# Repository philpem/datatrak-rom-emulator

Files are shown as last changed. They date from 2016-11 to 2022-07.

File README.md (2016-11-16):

EPROM Emulator for Datatrak Locator
===================================

This is a plug-in card which replaces the Datatrak "B7415" plug-in ROM card
used with the Locator Mk. II. Its purpose is to allow easier development of
alternative firmware for the Datatrak Locator II, and reverse engineering
of the hardware.

It consists of a 256Kx16 SRAM (512KiB) which can be loaded via an FTDI
FT240X USB serial FIFO and a Xilinx XC95144XL CPLD. The CPLD is programmed
using a JTAG cable.

Mod wires
---------
Rev 'A' boards require a 'mod wire' to be fitted between pin 135 of IC2
(the Xilinx CPLD) and either pin 10 of the SRAM or pin 37 of U3 (the
uppermost voltage level translator).

This wire carries D8 (level translated) from the level translator and SRAM
to the CPLD. Failure to install this wire will prevent D8 from being loaded
by the CPLD.

Known limitations
-----------------

  * The SRAM is powered from the target. Disconnecting target power will
    cause the loss of the data in the emulated EPROM.

    * It might be a good idea to break the power supply to the SRAM and
      feed it via two Schottky diodes: one from +3V3 and one from the FTDI's
      3V output.
      This way, the RAM will be maintained as long as either the USB or
      target is powered.

CPLD configuration
------------------
The CPLD must be programmed before the ROM emulator can be used.

  1. Apply 5V power through the DIN41612 target connector.
  2. 5V power is applied to pins A1 and B1 of the connector, while ground
     is applied to pins A16 and B16.
  3. 3.3V DC should be present on the output of voltage regulator IC1, and
     on JTAG connector X3.
  4. Connect a Xilinx Platform Cable USB (if using iMPACT) or Altera USB
     JTAG cable (if using OpenOCD) to JTAG connector X3.
  5. Use Xilinx iMPACT, OpenOCD or similar to program the CPLD.
    - It's probably easiest to use iMPACT.
  6. Disconnect the JTAG cable, 5V power, etc.
  7. Plug the pod into the Locator and load it.

FT240X configuration
--------------------
The FT240X needs to be programmed with FT-PROG.

  * Program CBUS5 to output the 24MHz clock.
    * This is used by the CPLD as a clock for the state machine.

Exfiltration mode
-----------------
This mode allows the target to access a specially-designated port to use as
a return-channel to the emulation control PC. Essentially, this is like a
secondary, lightweight, "printf".

When an access is made in a specially designated range (address lines
A8..A17 match a preset value), the value of address lines A0 through A7 is
latched, then sent to the FT240X as "write data".

This data may be read by the host PC at its convenience.

It would be nice to add an "infiltration mode" to send data from the PC to
the Locator, but "printf" was a higher priority.

Load protocol
-------------

The data in the FTDI buffer consists of Commands and Data. These are the
Commands which the state machine currently recognises:

  * 0b0000\_0000: NOP
    * Does nothing.
    * Used to reset the state machine to a known state.

  * 0b0000\_0001: Reset Memory Address Counter
    * Resets the memory address to zero

  * 0b0001\_Xemm: Set Mode
    * X: don't care
    * e: Exfiltration mode on/off
      * 0: Off
      * 1: On
    * mm: Mode
      * 00: Run
      * 01: Load

  * 0b0010\_nnnn: Write _nnnn_ words
    * nnnn: Number of words to write
    * Followed by _nnnn_ words of ROM data

  * 0b0100\_xxEE: Set Exfiltration Address
    * EE: Top two bits of exfiltration address (b17..b16)
    * Followed by a byte which contains bits 15..8 of the exfiltration
      address
    * Bits 7..0 are the exfiltration data itself

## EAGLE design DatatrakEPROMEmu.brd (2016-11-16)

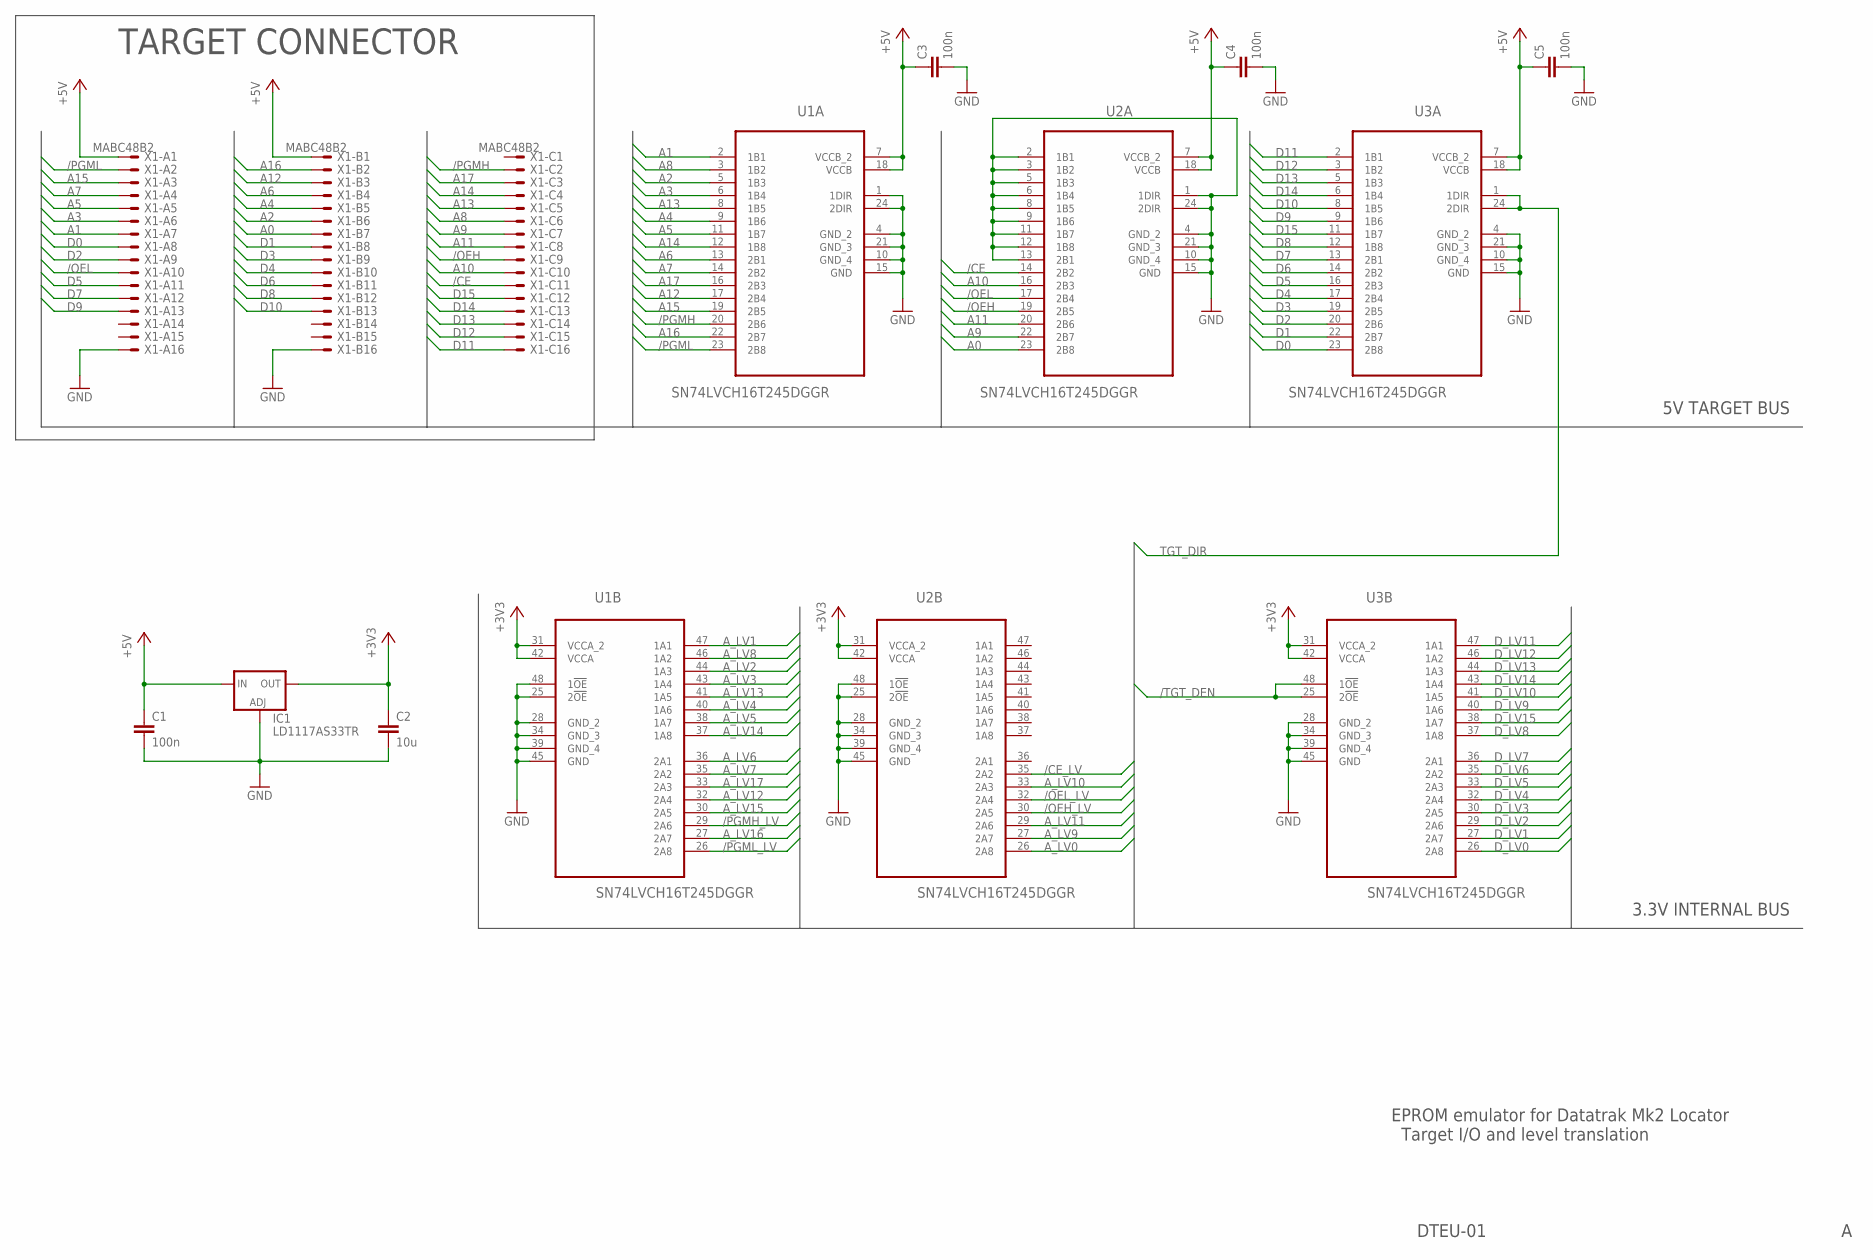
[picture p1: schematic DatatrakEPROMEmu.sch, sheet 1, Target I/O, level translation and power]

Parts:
C1, C3, C4, C5: 100n; C0805
C2: 10u; C0805
IC1: LD1117AS33TR; SOT223
U1, U2, U3: SN74LVCH16T245DGGR; SOP50P810X120-48N
X1: MABC48B2

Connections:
+3V3: C2.1, IC1.4 (OUT), U1.31 (VCCA_2), U1.42 (VCCA), U2.31 (VCCA_2), U2.42 (VCCA), U3.31 (VCCA_2), U3.42 (VCCA); also elsewhere on the board
+5V: C1.1, C3.1, C4.1, C5.1, IC1.3 (IN), U1.7 (VCCB_2), U1.18 (VCCB), U2.7 (VCCB_2), U2.18 (VCCB), U3.7 (VCCB_2), U3.18 (VCCB), X1.A1, X1.B1
/CE: U2.14 (2B2), X1.C11
/CE_LV: U2.35 (2A2); also elsewhere on the board
/OEH: U2.19 (2B5), X1.C9
/OEH_LV: U2.30 (2A5); also elsewhere on the board
/OEL: U2.17 (2B4), X1.A10
/OEL_LV: U2.32 (2A4); also elsewhere on the board
/PGMH: U1.20 (2B6), X1.C2
/PGMH_LV: U1.29 (2A6); also elsewhere on the board
/PGML: U1.23 (2B8), X1.A2
/PGML_LV: U1.26 (2A8); also elsewhere on the board
/TGT_DEN: U3.25 (2!OE), U3.48 (1!OE); also elsewhere on the board
A0: U2.23 (2B8), X1.B7
A1: U1.2 (1B1), X1.A7
A2: U1.5 (1B3), X1.B6
A3: U1.6 (1B4), X1.A6
A4: U1.9 (1B6), X1.B5
A5: U1.11 (1B7), X1.A5
A6: U1.13 (2B1), X1.B4
A7: U1.14 (2B2), X1.A4
A8: U1.3 (1B2), X1.C6
A9: U2.22 (2B7), X1.C7
A10: U2.16 (2B3), X1.C10
A11: U2.20 (2B6), X1.C8
A12: U1.17 (2B4), X1.B3
A13: U1.8 (1B5), X1.C5
A14: U1.12 (1B8), X1.C4
A15: U1.19 (2B5), X1.A3
A16: U1.22 (2B7), X1.B2
A17: U1.16 (2B3), X1.C3
A_LV0: U2.26 (2A8); also elsewhere on the board
A_LV1: U1.47 (1A1); also elsewhere on the board
A_LV2: U1.44 (1A3); also elsewhere on the board
A_LV3: U1.43 (1A4); also elsewhere on the board
A_LV4: U1.40 (1A6); also elsewhere on the board
A_LV5: U1.38 (1A7); also elsewhere on the board
A_LV6: U1.36 (2A1); also elsewhere on the board
A_LV7: U1.35 (2A2); also elsewhere on the board
A_LV8: U1.46 (1A2); also elsewhere on the board
A_LV9: U2.27 (2A7); also elsewhere on the board
A_LV10: U2.33 (2A3); also elsewhere on the board
A_LV11: U2.29 (2A6); also elsewhere on the board
A_LV12: U1.32 (2A4); also elsewhere on the board
A_LV13: U1.41 (1A5); also elsewhere on the board
A_LV14: U1.37 (1A8); also elsewhere on the board
A_LV15: U1.30 (2A5); also elsewhere on the board
A_LV16: U1.27 (2A7); also elsewhere on the board
A_LV17: U1.33 (2A3); also elsewhere on the board
D0: U3.23 (2B8), X1.A8
D1: U3.22 (2B7), X1.B8
D2: U3.20 (2B6), X1.A9
D3: U3.19 (2B5), X1.B9
D4: U3.17 (2B4), X1.B10
D5: U3.16 (2B3), X1.A11
D6: U3.14 (2B2), X1.B11
D7: U3.13 (2B1), X1.A12
D8: U3.12 (1B8), X1.B12
D9: U3.9 (1B6), X1.A13
D10: U3.8 (1B5), X1.B13
D11: U3.2 (1B1), X1.C16
D12: U3.3 (1B2), X1.C15
D13: U3.5 (1B3), X1.C14
D14: U3.6 (1B4), X1.C13
D15: U3.11 (1B7), X1.C12
D_LV0: U3.26 (2A8); also elsewhere on the board
D_LV1: U3.27 (2A7); also elsewhere on the board
D_LV2: U3.29 (2A6); also elsewhere on the board
D_LV3: U3.30 (2A5); also elsewhere on the board
D_LV4: U3.32 (2A4); also elsewhere on the board
D_LV5: U3.33 (2A3); also elsewhere on the board
D_LV6: U3.35 (2A2); also elsewhere on the board
D_LV7: U3.36 (2A1); also elsewhere on the board
D_LV8: U3.37 (1A8); also elsewhere on the board
D_LV9: U3.40 (1A6); also elsewhere on the board
D_LV10: U3.41 (1A5); also elsewhere on the board
D_LV11: U3.47 (1A1); also elsewhere on the board
D_LV12: U3.46 (1A2); also elsewhere on the board
D_LV13: U3.44 (1A3); also elsewhere on the board
D_LV14: U3.43 (1A4); also elsewhere on the board
D_LV15: U3.38 (1A7); also elsewhere on the board
GND: C1.2, C2.2, C3.2, C4.2, C5.2, IC1.1 (ADJ), U1.1 (1DIR), U1.4 (GND_2), U1.10 (GND_4), U1.15 (GND), U1.21 (GND_3), U1.24 (2DIR), U1.25 (2!OE), U1.28 (GND_2), U1.34 (GND_3), U1.39 (GND_4), U1.45 (GND), U1.48 (1!OE), U2.1 (1DIR), U2.2 (1B1), U2.3 (1B2), U2.4 (GND_2), U2.5 (1B3), U2.6 (1B4), U2.8 (1B5), U2.9 (1B6), U2.10 (GND_4), U2.11 (1B7), U2.12 (1B8), U2.13 (2B1), U2.15 (GND), U2.21 (GND_3), U2.24 (2DIR), U2.25 (2!OE), U2.28 (GND_2), U2.34 (GND_3), U2.39 (GND_4), U2.45 (GND), U2.48 (1!OE), U3.4 (GND_2), U3.10 (GND_4), U3.15 (GND), U3.21 (GND_3), U3.28 (GND_2), U3.34 (GND_3), U3.39 (GND_4), U3.45 (GND), X1.A16, X1.B16; also elsewhere on the board
TGT_DIR: U3.1 (1DIR), U3.24 (2DIR); also elsewhere on the board

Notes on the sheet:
TARGET CONNECTOR
5V TARGET BUS
3.3V INTERNAL BUS
DTEU-01
EPROM emulator for Datatrak Mk2 Locator Target I/O and level translation

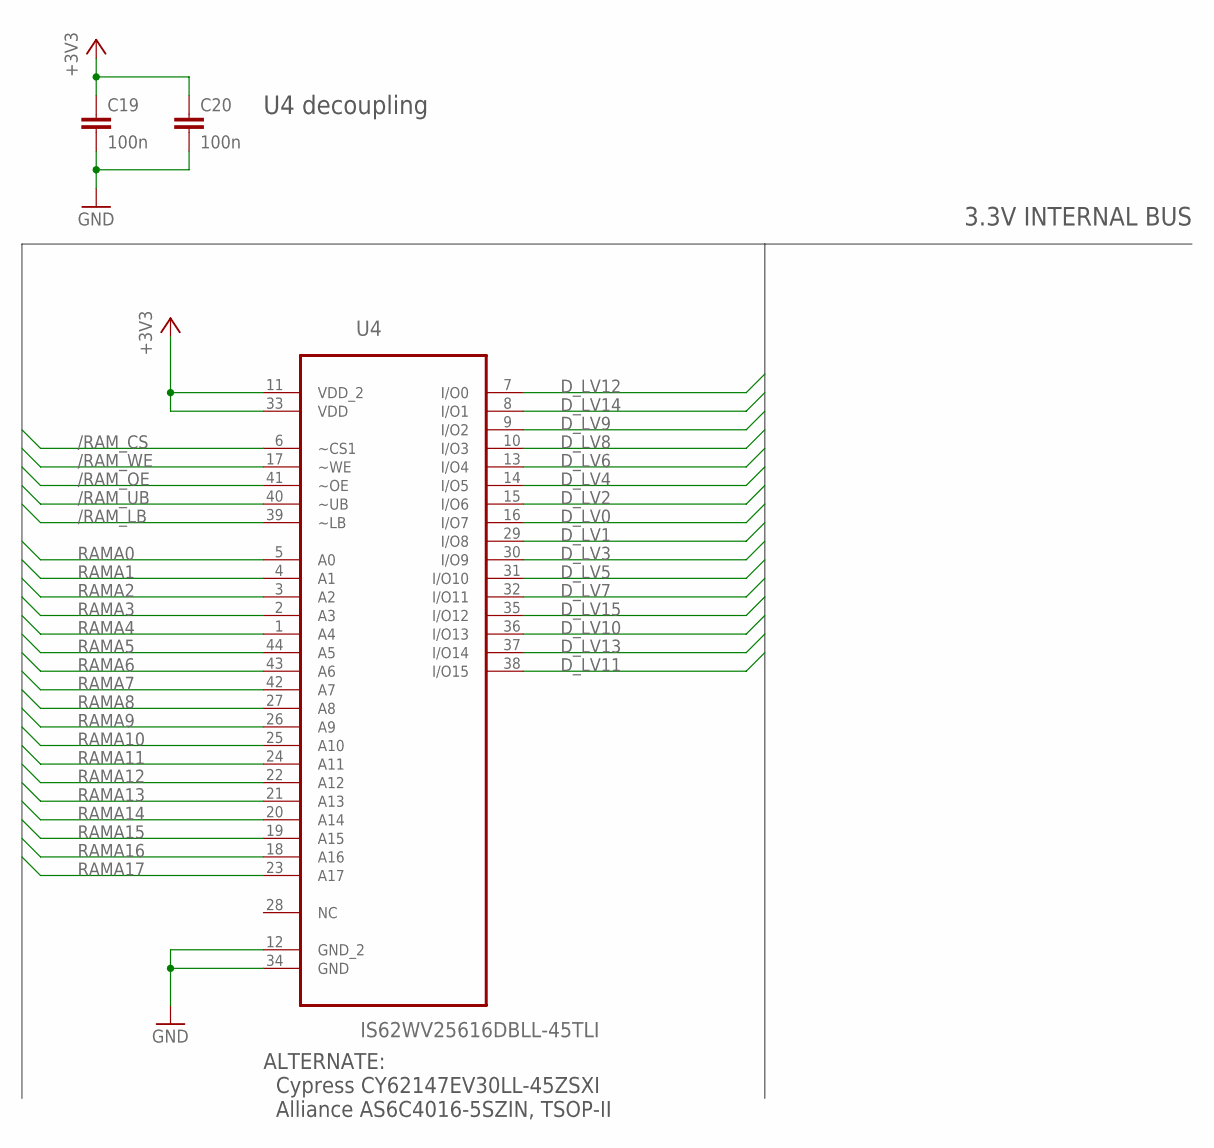
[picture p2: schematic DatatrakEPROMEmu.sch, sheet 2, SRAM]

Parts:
C19, C20: 100n; C0805
U4: IS62WV25616DBLL-45TLI; SOP80P1176X120-44N

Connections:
+3V3: C19.1, C20.1, U4.11 (VDD_2), U4.33 (VDD); also elsewhere on the board
/RAM_CS: U4.6 (~CS1); also elsewhere on the board
/RAM_LB: U4.39 (~LB); also elsewhere on the board
/RAM_OE: U4.41 (~OE); also elsewhere on the board
/RAM_UB: U4.40 (~UB); also elsewhere on the board
/RAM_WE: U4.17 (~WE); also elsewhere on the board
D_LV0: U4.16 (I/O7); also elsewhere on the board
D_LV1: U4.29 (I/O8); also elsewhere on the board
D_LV2: U4.15 (I/O6); also elsewhere on the board
D_LV3: U4.30 (I/O9); also elsewhere on the board
D_LV4: U4.14 (I/O5); also elsewhere on the board
D_LV5: U4.31 (I/O10); also elsewhere on the board
D_LV6: U4.13 (I/O4); also elsewhere on the board
D_LV7: U4.32 (I/O11); also elsewhere on the board
D_LV8: U4.10 (I/O3); also elsewhere on the board
D_LV9: U4.9 (I/O2); also elsewhere on the board
D_LV10: U4.36 (I/O13); also elsewhere on the board
D_LV11: U4.38 (I/O15); also elsewhere on the board
D_LV12: U4.7 (I/O0); also elsewhere on the board
D_LV13: U4.37 (I/O14); also elsewhere on the board
D_LV14: U4.8 (I/O1); also elsewhere on the board
D_LV15: U4.35 (I/O12); also elsewhere on the board
GND: C19.2, C20.2, U4.12 (GND_2), U4.34 (GND); also elsewhere on the board
RAMA0: U4.5 (A0); also elsewhere on the board
RAMA1: U4.4 (A1); also elsewhere on the board
RAMA2: U4.3 (A2); also elsewhere on the board
RAMA3: U4.2 (A3); also elsewhere on the board
RAMA4: U4.1 (A4); also elsewhere on the board
RAMA5: U4.44 (A5); also elsewhere on the board
RAMA6: U4.43 (A6); also elsewhere on the board
RAMA7: U4.42 (A7); also elsewhere on the board
RAMA8: U4.27 (A8); also elsewhere on the board
RAMA9: U4.26 (A9); also elsewhere on the board
RAMA10: U4.25 (A10); also elsewhere on the board
RAMA11: U4.24 (A11); also elsewhere on the board
RAMA12: U4.22 (A12); also elsewhere on the board
RAMA13: U4.21 (A13); also elsewhere on the board
RAMA14: U4.20 (A14); also elsewhere on the board
RAMA15: U4.19 (A15); also elsewhere on the board
RAMA16: U4.18 (A16); also elsewhere on the board
RAMA17: U4.23 (A17); also elsewhere on the board

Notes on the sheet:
3.3V INTERNAL BUS
ALTERNATE: Cypress CY62147EV30LL-45ZSXI Alliance AS6C4016-5SZIN, TSOP-II
U4 decoupling

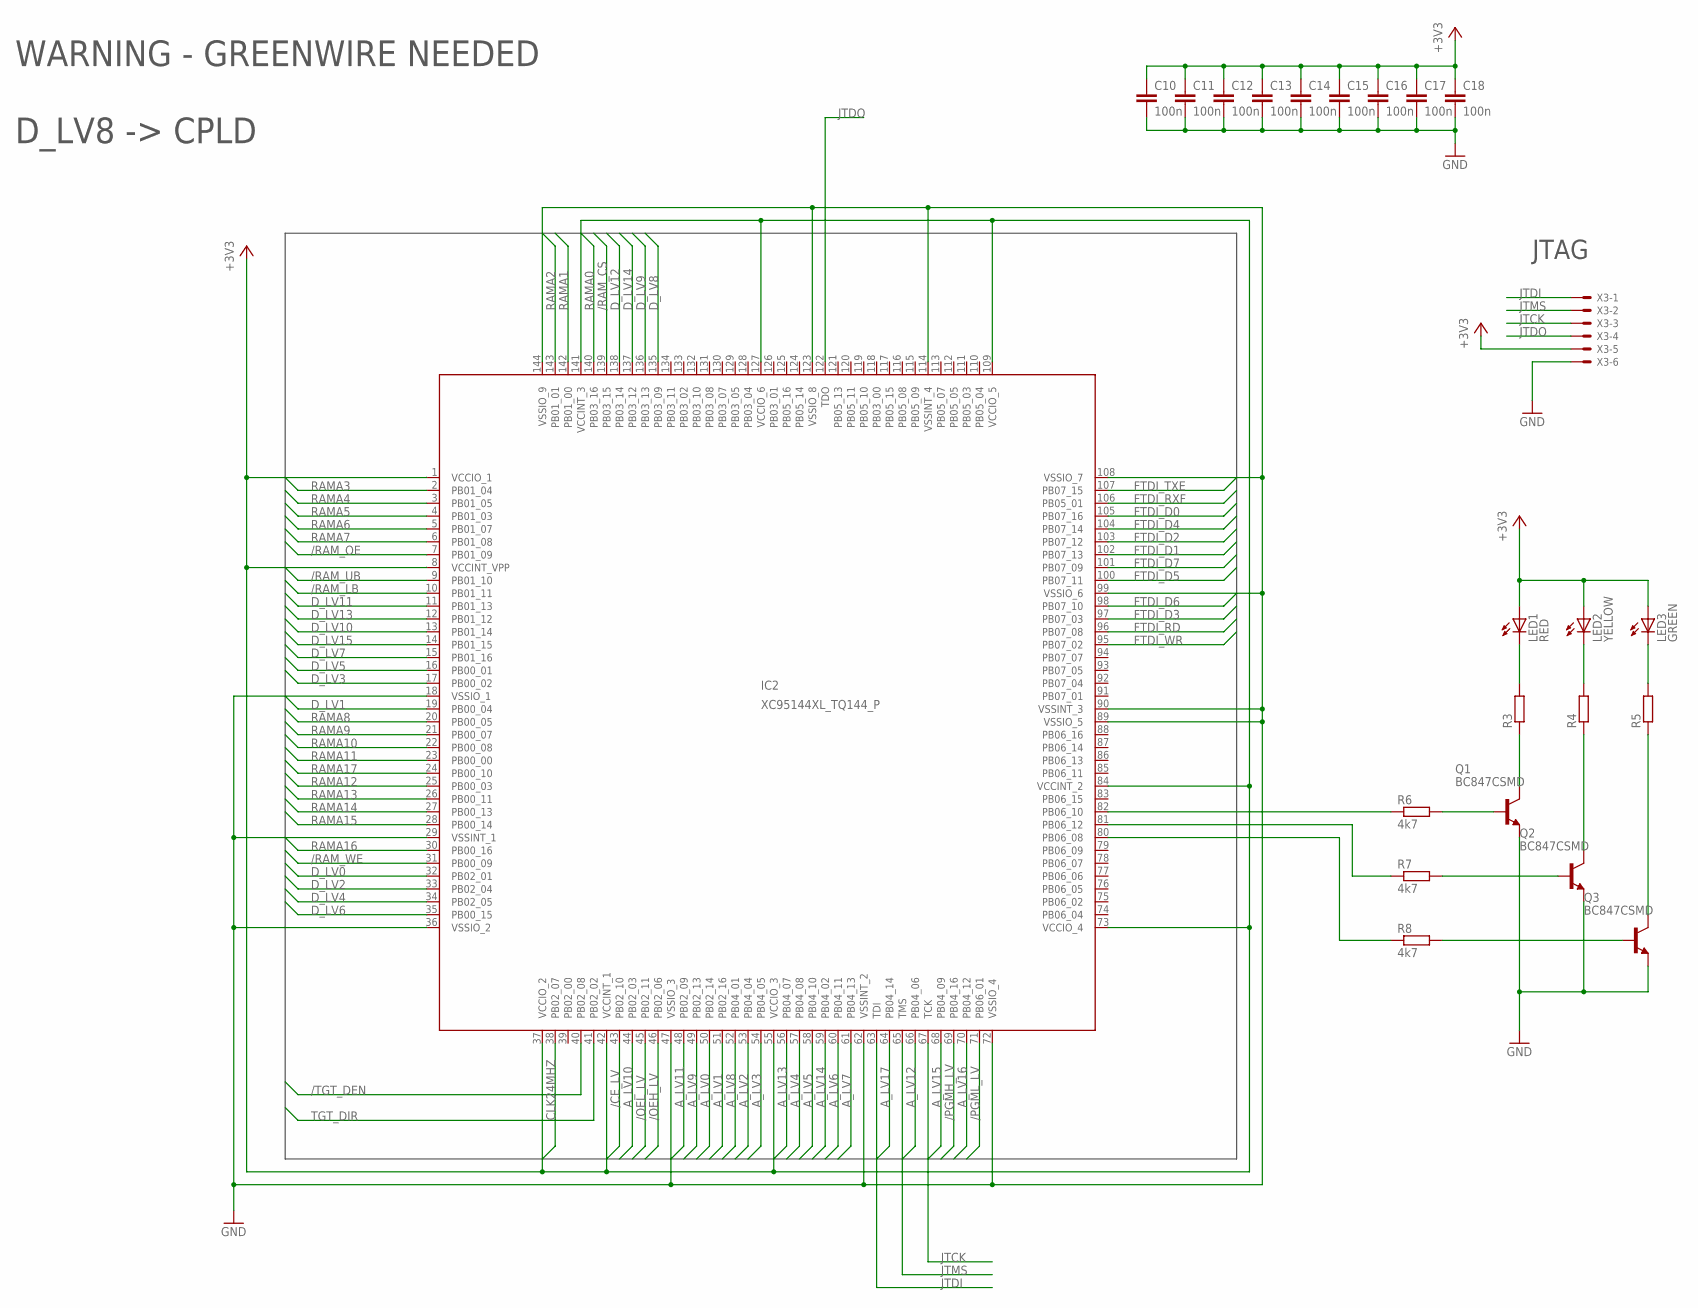
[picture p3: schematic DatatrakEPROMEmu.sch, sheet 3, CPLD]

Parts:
C10, C11, C12, C13, C14, C15, C16, C17, C18: 100n; C0805
IC2: XC95144XL_TQ144_P; TQ144
LED1: RED; SML0805
LED2: YELLOW; SML0805
LED3: GREEN; SML0805
Q1, Q2, Q3: BC847CSMD; SOT23
R3, R4, R5: R-EU_R0805; R0805
R6, R7, R8: 4k7; R0805
X3: 22-23-2061

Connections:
+3V3: C10.1, C11.1, C12.1, C13.1, C14.1, C15.1, C16.1, C17.1, C18.1, IC2.1 (VCCIO_1), IC2.8 (VCCINT_VPP), IC2.37 (VCCIO_2), IC2.42 (VCCINT_1), IC2.55 (VCCIO_3), IC2.73 (VCCIO_4), IC2.84 (VCCINT_2), IC2.109 (VCCIO_5), IC2.127 (VCCIO_6), IC2.141 (VCCINT_3), LED1.A, LED2.A, LED3.A, X3.5; also elsewhere on the board
/CE_LV: IC2.43 (PB02_10); also elsewhere on the board
/OEH_LV: IC2.46 (PB02_06); also elsewhere on the board
/OEL_LV: IC2.45 (PB02_11); also elsewhere on the board
/PGMH_LV: IC2.69 (PB04_16); also elsewhere on the board
/PGML_LV: IC2.71 (PB06_01); also elsewhere on the board
/RAM_CS: IC2.139 (PB03_15); also elsewhere on the board
/RAM_LB: IC2.10 (PB01_11); also elsewhere on the board
/RAM_OE: IC2.7 (PB01_09); also elsewhere on the board
/RAM_UB: IC2.9 (PB01_10); also elsewhere on the board
/RAM_WE: IC2.31 (PB00_09); also elsewhere on the board
/TGT_DEN: IC2.40 (PB02_08); also elsewhere on the board
A_LV0: IC2.50 (PB02_14); also elsewhere on the board
A_LV1: IC2.51 (PB02_16); also elsewhere on the board
A_LV2: IC2.53 (PB04_04); also elsewhere on the board
A_LV3: IC2.54 (PB04_05); also elsewhere on the board
A_LV4: IC2.57 (PB04_08); also elsewhere on the board
A_LV5: IC2.58 (PB04_10); also elsewhere on the board
A_LV6: IC2.60 (PB04_11); also elsewhere on the board
A_LV7: IC2.61 (PB04_13); also elsewhere on the board
A_LV8: IC2.52 (PB04_01); also elsewhere on the board
A_LV9: IC2.49 (PB02_13); also elsewhere on the board
A_LV10: IC2.44 (PB02_03); also elsewhere on the board
A_LV11: IC2.48 (PB02_09); also elsewhere on the board
A_LV12: IC2.66 (PB04_06); also elsewhere on the board
A_LV13: IC2.56 (PB04_07); also elsewhere on the board
A_LV14: IC2.59 (PB04_02); also elsewhere on the board
A_LV15: IC2.68 (PB04_09); also elsewhere on the board
A_LV16: IC2.70 (PB04_12); also elsewhere on the board
A_LV17: IC2.64 (PB04_14); also elsewhere on the board
CLK24MHZ: IC2.38 (PB02_07); also elsewhere on the board
D_LV0: IC2.32 (PB02_01); also elsewhere on the board
D_LV1: IC2.19 (PB00_04); also elsewhere on the board
D_LV2: IC2.33 (PB02_04); also elsewhere on the board
D_LV3: IC2.17 (PB00_02); also elsewhere on the board
D_LV4: IC2.34 (PB02_05); also elsewhere on the board
D_LV5: IC2.16 (PB00_01); also elsewhere on the board
D_LV6: IC2.35 (PB00_15); also elsewhere on the board
D_LV7: IC2.15 (PB01_16); also elsewhere on the board
D_LV8: IC2.135 (PB03_09); also elsewhere on the board
D_LV9: IC2.136 (PB03_13); also elsewhere on the board
D_LV10: IC2.13 (PB01_14); also elsewhere on the board
D_LV11: IC2.11 (PB01_13); also elsewhere on the board
D_LV12: IC2.138 (PB03_14); also elsewhere on the board
D_LV13: IC2.12 (PB01_12); also elsewhere on the board
D_LV14: IC2.137 (PB03_12); also elsewhere on the board
D_LV15: IC2.14 (PB01_15); also elsewhere on the board
FTDI_D0: IC2.105 (PB07_16); also elsewhere on the board
FTDI_D1: IC2.102 (PB07_13); also elsewhere on the board
FTDI_D2: IC2.103 (PB07_12); also elsewhere on the board
FTDI_D3: IC2.97 (PB07_03); also elsewhere on the board
FTDI_D4: IC2.104 (PB07_14); also elsewhere on the board
FTDI_D5: IC2.100 (PB07_11); also elsewhere on the board
FTDI_D6: IC2.98 (PB07_10); also elsewhere on the board
FTDI_D7: IC2.101 (PB07_09); also elsewhere on the board
FTDI_RD: IC2.96 (PB07_08); also elsewhere on the board
FTDI_RXF: IC2.106 (PB05_01); also elsewhere on the board
FTDI_TXE: IC2.107 (PB07_15); also elsewhere on the board
FTDI_WR: IC2.95 (PB07_02); also elsewhere on the board
GND: C10.2, C11.2, C12.2, C13.2, C14.2, C15.2, C16.2, C17.2, C18.2, IC2.18 (VSSIO_1), IC2.29 (VSSINT_1), IC2.36 (VSSIO_2), IC2.47 (VSSIO_3), IC2.62 (VSSINT_2), IC2.72 (VSSIO_4), IC2.89 (VSSIO_5), IC2.90 (VSSINT_3), IC2.99 (VSSIO_6), IC2.108 (VSSIO_7), IC2.114 (VSSINT_4), IC2.123 (VSSIO_8), IC2.144 (VSSIO_9), Q1.2 (E), Q2.2 (E), Q3.2 (E), X3.6; also elsewhere on the board
JTCK: IC2.67 (TCK), X3.3
JTDI: IC2.63 (TDI), X3.1
JTDO: IC2.122 (TDO), X3.4
JTMS: IC2.65 (TMS), X3.2
unnamed: Q1.3 (C), R3.1
unnamed: Q2.3 (C), R4.1
unnamed: Q3.3 (C), R5.1
unnamed: LED1.C, R3.2
unnamed: LED2.C, R4.2
unnamed: LED3.C, R5.2
unnamed: IC2.82 (PB06_10), R6.1
unnamed: IC2.81 (PB06_12), R7.1
unnamed: IC2.80 (PB06_08), R8.1
unnamed: Q1.1 (B), R6.2
unnamed: Q2.1 (B), R7.2
unnamed: Q3.1 (B), R8.2
RAMA0: IC2.140 (PB03_16); also elsewhere on the board
RAMA1: IC2.142 (PB01_00); also elsewhere on the board
RAMA2: IC2.143 (PB01_01); also elsewhere on the board
RAMA3: IC2.2 (PB01_04); also elsewhere on the board
RAMA4: IC2.3 (PB01_05); also elsewhere on the board
RAMA5: IC2.4 (PB01_03); also elsewhere on the board
RAMA6: IC2.5 (PB01_07); also elsewhere on the board
RAMA7: IC2.6 (PB01_08); also elsewhere on the board
RAMA8: IC2.20 (PB00_05); also elsewhere on the board
RAMA9: IC2.21 (PB00_07); also elsewhere on the board
RAMA10: IC2.22 (PB00_08); also elsewhere on the board
RAMA11: IC2.23 (PB00_00); also elsewhere on the board
RAMA12: IC2.25 (PB00_03); also elsewhere on the board
RAMA13: IC2.26 (PB00_11); also elsewhere on the board
RAMA14: IC2.27 (PB00_13); also elsewhere on the board
RAMA15: IC2.28 (PB00_14); also elsewhere on the board
RAMA16: IC2.30 (PB00_16); also elsewhere on the board
RAMA17: IC2.24 (PB00_10); also elsewhere on the board
TGT_DIR: IC2.41 (PB02_02); also elsewhere on the board

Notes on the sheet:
JTAG
WARNING - GREENWIRE NEEDED D_LV8 -> CPLD

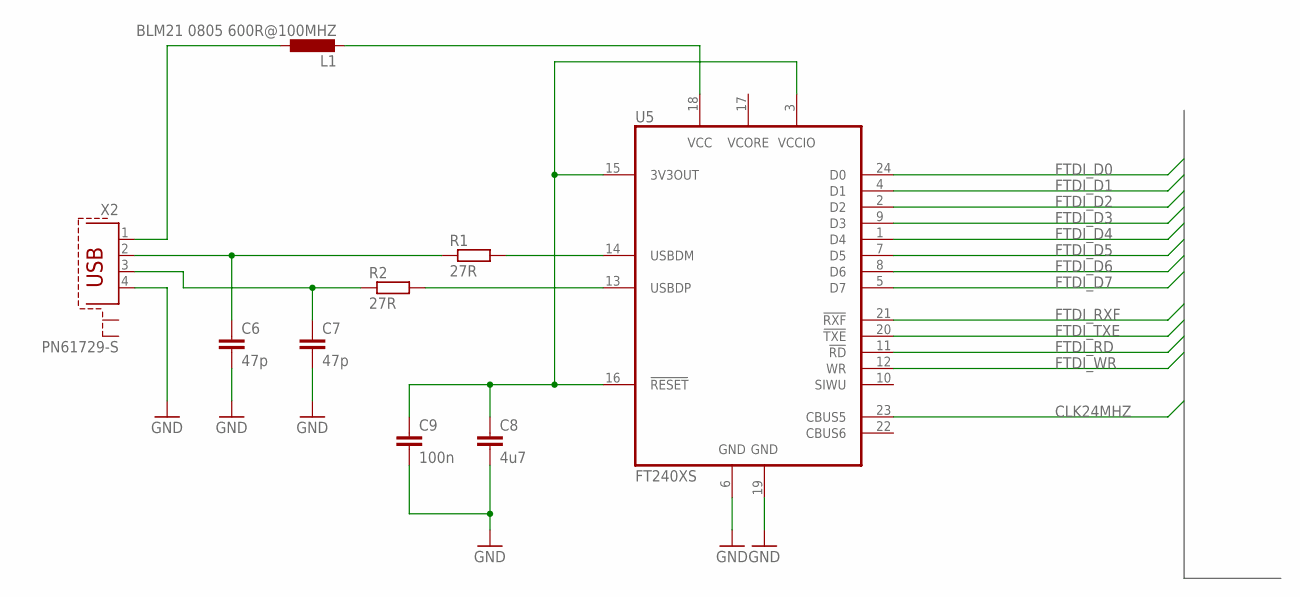
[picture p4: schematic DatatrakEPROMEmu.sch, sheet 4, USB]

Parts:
C6, C7: 47p; C0805
C8: 4u7; C0805
C9: 100n; C0805
L1: BLM21 0805 600R@100MHZ; L2012C
R1, R2: 27R; R0805
U5: FT240XS; SSOP24
X2: PN61729-S

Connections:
CLK24MHZ: U5.23 (CBUS5); also elsewhere on the board
FTDI_D0: U5.24 (D0); also elsewhere on the board
FTDI_D1: U5.4 (D1); also elsewhere on the board
FTDI_D2: U5.2 (D2); also elsewhere on the board
FTDI_D3: U5.9 (D3); also elsewhere on the board
FTDI_D4: U5.1 (D4); also elsewhere on the board
FTDI_D5: U5.7 (D5); also elsewhere on the board
FTDI_D6: U5.8 (D6); also elsewhere on the board
FTDI_D7: U5.5 (D7); also elsewhere on the board
FTDI_RD: U5.11 (!RD!); also elsewhere on the board
FTDI_RXF: U5.21 (!RXF!); also elsewhere on the board
FTDI_TXE: U5.20 (!TXE!); also elsewhere on the board
FTDI_WR: U5.12 (WR); also elsewhere on the board
GND: C6.2, C7.2, C8.2, C9.2, U5.6 (GND), U5.19 (GND), X2.4; also elsewhere on the board
unnamed: L1.2, U5.18 (VCC)
unnamed: L1.1, X2.1
unnamed: R1.2, U5.14 (USBDM)
unnamed: R2.2, U5.13 (USBDP)
unnamed: C6.1, R1.1, X2.2
unnamed: C7.1, R2.1, X2.3
unnamed: C8.1, C9.1, U5.3 (VCCIO), U5.15 (3V3OUT), U5.16 (!RESET!)

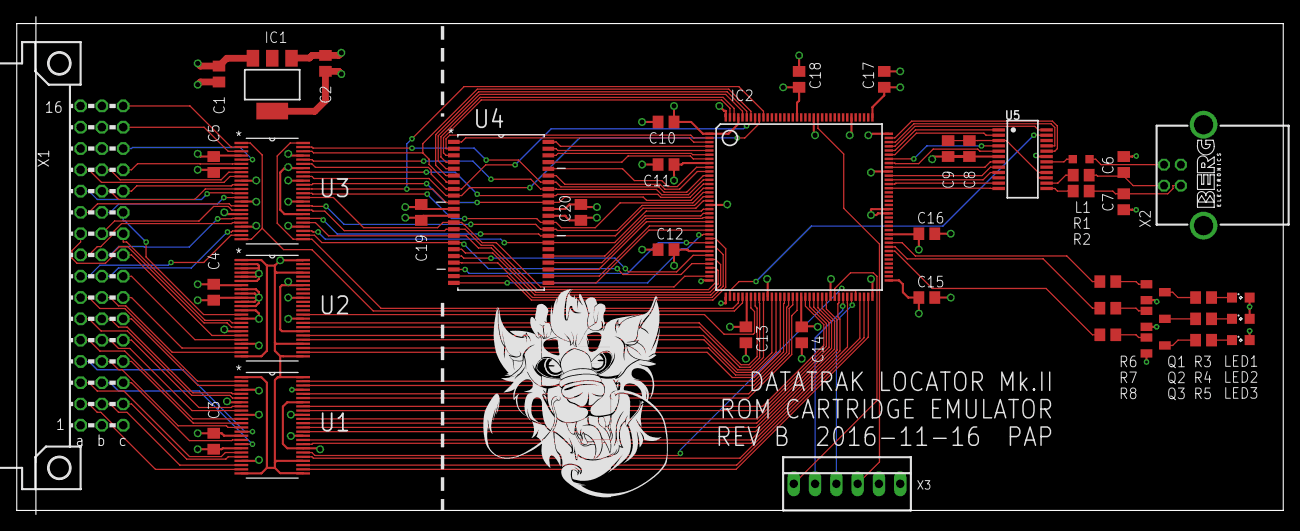
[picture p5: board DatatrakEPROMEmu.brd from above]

Board: 4 copper layers, 151.1 x 59.4 mm, 46 parts (0 on the bottom side), 142 nets.

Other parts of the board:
U$1: CHAOSLOGO

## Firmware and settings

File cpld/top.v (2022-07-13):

`timescale 1ns / 1ps
//////////////////////////////////////////////////////////////////////////////////
// Company: 
// Engineer: 
// 
// Create Date:    01:23:44 10/08/2016 
// Design Name: 
// Module Name:    top 
// Project Name: 
// Target Devices: 
// Tool versions: 
// Description: 
//
// Dependencies: 
//
// Revision: 
// Revision 0.01 - File Created
// Additional Comments: 
//
//////////////////////////////////////////////////////////////////////////////////
module top(
    input clk24MHz,				// 24MHz Clock from FT240X

	 // --- Target I/O lines ---
    input tgt_nPGMH,				// Program High -- from target
    input tgt_nPGML,				// Program Low -- from target
    input [17:0] addr_bus,		// Target Address bus
										//		Target drives via buffer -- buffer always active
    inout [15:0] data_bus,		// Target/SRAM Data bus -- shared between target and SRAM
										//		CPLD drives direct (buffer disabled) when loading
										//		Target drives via buffer (buffer active) when running
										//	   --> Output Enable: target_dbusbuf_en
										//    --> Direction:     target_dbusbuf_dir
    input tgt_nCE,				// Chip enable from target
    input tgt_nOEL,				// OE Low from target
    input tgt_nOEH,				// OE High from target
	
	 // --- Target I/O control ---
    output target_dbusbuf_dir,	// Data Bus Buffer Direction -- 0= from target to SRAM, 1= from SRAM to target
    output target_dbusbuf_en,		// Data Bus Buffer Enable -- 0= target data drive enabled
	 
	 // --- FT240X USB FIFO ---
    inout [7:0] ft240x_d,		// FT240X 8-bit FIFO bus
    output ft240x_nRD,			// FT240X Read Strobe (H->L edge triggered)
    output ft240x_nWR,			// FT240X Write Strobe (H->L edge triggered)
    input ft240x_TXE,			// FT240X Transmit FIFO Full: When high, do not write more bytes to the FIFO
    input ft240x_RXF,			//	FT240X Receive FIFO Empty: When high, do not read data from the FIFO
	 	 
	 // --- SRAM interface ---
    output [17:0] sram_addr,	// SRAM Address bus -- shared between target and CPLD
										//		CPLD drives direct (buffer disabled) when loading
										//		Target drives via buffer (buffer active) when running
    output sram_nCS,				// SRAM chip select
    output sram_nWE,				// SRAM write enable
	 output sram_nOE,				// SRAM output enable
    output sram_nUB,				// SRAM upper byte enable
    output sram_nLB,				// SRAM lower byte enable
	 
	 // --- LEDs ---
	 output led_red,				// Red LED, 1=on
	 output led_amber,			// Amber LED, 1=on
	 output led_green				// Green LED, 1=on
    );

/////////////////////////////////////////////////////////////////////////////
// MODE register

parameter MODE_LOAD	= 2'h0;		// Code is being loaded into the SRAM
parameter MODE_RUN	= 2'h1;		// Target is able to access the SRAM
// TODO: does Exfiltration need a separate MODE?

// Mode register
reg [1:0] mode;


/////////////////////////////////////////////////////////////////////////////
// Exfiltration mode logic

// Exfiltration enabled?
reg exfiltration_enable;

// Exfiltration address register
reg [17:8] exfiltration_addr;

// Exfiltration mode address match
wire exfiltration_addr_match =
	(mode == MODE_RUN) &&
	(addr_bus[17:8] == exfiltration_addr[17:8]);


/////////////////////////////////////////////////////////////////////////////
// SRAM interface

// Address counter
reg[17:0] addr_counter;

// Data output latch
reg[15:0] sram_write_latch;

// SRAM Address bus:
//		If the target is driving the address bus, then the SRAM address is
//		  sourced from the target address bus.
//		Otherwise it's sourced from the address counter.
assign sram_addr = ((mode == MODE_LOAD) ? addr_counter : addr_bus);

// Data bus:
//    If we're in LOAD mode, both the low and high words should be driven
//    from the FTDI data bus.
//       The Low Strobe and High Strobe are used to determine whether it's
//       the MSB or LSB which is written.
//    If we're in RUN mode, this should be Hi-Z.
//        TODO: If we ever want to implement a "debug read" port, this won't always be Hi-Z
//              the SRAM /CE logic will have to be changed too (gate it from the "read port address decode" line)
assign data_bus = (mode == MODE_LOAD) ? sram_write_latch : 16'hZZZZ;


/////////////////////////////////////////////////////////////////////////////
// Bus buffer enable logic

// FIXME: All of these need checking

// Data bus buffer enable
//    This is enabled (target can drive address bus) if we're in RUN mode
assign target_dbusbuf_en =
	!(									// Active low!
		(mode == MODE_RUN) &&			// Running, and
		!tgt_nCE &&							// Target chip enable asserted, and
		(!tgt_nOEL || !tgt_nOEH)		// Either target OELow or OEHigh asserted
	);

// Data bus buffer direction
//    This is EPROM => Target all the time.
//    NOTE: If we implement the read port, we need to add more logic here
assign target_dbusbuf_dir = 1'b1;


/////////////////////////////////////////////////////////////////////////////
// System state machine

parameter STATE_NEXTCMD				= 5'h00;
parameter STATE_WAITCMD 			= 5'h01;	// Wait for FTDI to signal RXE=0 (byte ready)
parameter STATE_CMD_PRERX  		= 5'h02;	// RX# going low just before command byte is read by the FSM
parameter STATE_GETCMD  			= 5'h03;	// Get and decode a new command from the FTDI
parameter STATE_SETMODE				= 5'h04;	// SET MODE
parameter STATE_WRITE_1				= 5'h05;	// Write words 1/9
parameter STATE_WRITE_HIGH_REQ	= 5'h06;	// Write words 2/9
parameter STATE_WRITE_HIGH_LATCH	= 5'h07;	// Write words 3/9
parameter STATE_WRITE_WAIT			= 5'h08;	// Write words 4/9
parameter STATE_WRITE_LOW_REQ		= 5'h09;	// Write words 5/9
parameter STATE_WRITE_LOW_LATCH	= 5'h0A;	// Write words 6/9
parameter STATE_WRITE_STROBE_WR	= 5'h0B;	// Write words 7/9
parameter STATE_WRITE_RELEASE_WR	= 5'h0C;	// Write words 8/9
parameter STATE_WRITE_INC_ADDR	= 5'h0D;	// Write words 9/9
parameter STATE_WRITE_EXFIL_A		= 5'h0E;	// Write Exfiltration Address 1/2
parameter STATE_WRITE_EXFIL_B		= 5'h0F;	// Write Exfiltration Address 2/3
parameter STATE_WRITE_EXFIL_C		= 5'h10;	// Write Exfiltration Address 3/3

reg [4:0] state;
reg [3:0] count;

reg status_led;
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

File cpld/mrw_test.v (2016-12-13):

`timescale 1ns / 100ps

////////////////////////////////////////////////////////////////////////////////
// Company: 
// Engineer:
//
// Create Date:   12:26:38 12/11/2016
// Design Name:   top
// Module Name:   C:/Documents and Settings/Administrator/Desktop/dtrkeprom_cpld/mrw_test.v
// Project Name:  dtrk_eprom_emu
// Target Device:  
// Tool versions:  
// Description: 
//
// Verilog Test Fixture created by ISE for module: top
//
// Dependencies:
// 
// Revision:
// Revision 0.01 - File Created
// Additional Comments:
// 
////////////////////////////////////////////////////////////////////////////////

module mrw_test;

	// Inputs
	reg clk24MHz;
	reg tgt_nPGMH;
	reg tgt_nPGML;
	reg [17:0] addr_bus;
	wire tgt_nCE;
	wire tgt_nOEL;
	wire tgt_nOEH;
	reg ft240x_TXE;
	reg ft240x_RXF;

	// Outputs
	wire target_dbusbuf_dir;
	wire target_dbusbuf_en;
	wire ft240x_nRD;
	wire ft240x_nWR;
	wire [17:0] sram_addr;
	wire sram_nCS;
	wire sram_nWE;
	wire sram_nOE;
	wire sram_nUB;
	wire sram_nLB;
	wire led_red;
	wire led_amber;
	wire led_green;

	// Bidirs
	wire [15:0] data_bus;
	wire [7:0] ft240x_d;

	// Instantiate the Unit Under Test (UUT)
	top uut (
		.clk24MHz(clk24MHz), 
		.tgt_nPGMH(tgt_nPGMH), 
		.tgt_nPGML(tgt_nPGML), 
		.addr_bus(addr_bus), 
		.data_bus(data_bus), 
		.tgt_nCE(tgt_nCE), 
		.tgt_nOEL(tgt_nOEL), 
		.tgt_nOEH(tgt_nOEH), 
		.target_dbusbuf_dir(target_dbusbuf_dir), 
		.target_dbusbuf_en(target_dbusbuf_en), 
		.ft240x_d(ft240x_d), 
		.ft240x_nRD(ft240x_nRD), 
		.ft240x_nWR(ft240x_nWR), 
		.ft240x_TXE(ft240x_TXE), 
		.ft240x_RXF(ft240x_RXF), 
		.sram_addr(sram_addr), 
		.sram_nCS(sram_nCS), 
		.sram_nWE(sram_nWE), 
		.sram_nOE(sram_nOE), 
		.sram_nUB(sram_nUB), 
		.sram_nLB(sram_nLB), 
		.led_red(led_red), 
		.led_amber(led_amber), 
		.led_green(led_green)
	);

	initial begin
		// Initialize Inputs
		clk24MHz = 0;
		tgt_nPGMH = 0;
		tgt_nPGML = 0;
		
		ft240x_TXE = 1;
		ft240x_RXF = 0;	// initially, there's something to read

		// Wait 100 ns for global reset to finish
		#100;
        
		// Add stimulus here
	end
	
	
	// Generate clock -- every 84ns invert it (about 6MHz)
	//       --> changed to 12MHz because the RAM has a 55ns access time
	//           thus the max Fclk the RAM would allow is ~18MHz
	//       --> changed to 6MHz because of FT240X access time requirements
	always
		#84 clk24MHz = ~clk24MHz;
		
		
	reg [7:0] ft_data_o;
	reg [7:0] ft_addr;

	initial begin
		ft_addr = 0;
	end

	always @(negedge ft240x_nRD) begin
		case (ft_addr)
		  0: ft_data_o <= 8'h10;		// set load mode
		  1: ft_data_o <= 8'h01;		// reset address counter
		  2: ft_data_o <= 8'h20;		// write 16 words

		  3: ft_data_o <= 8'h12;		// word 1
		  4: ft_data_o <= 8'h34;		// 

		  5: ft_data_o <= 8'h12;		// word 2
		  6: ft_data_o <= 8'h34;		// 

		  7: ft_data_o <= 8'h12;		// word 3
		  8: ft_data_o <= 8'h34;		// 

		  9: ft_data_o <= 8'h12;		// word 4
		 10: ft_data_o <= 8'h34;		// 

		 11: ft_data_o <= 8'h12;		// word 5
		 12: ft_data_o <= 8'h34;		// 

		 13: ft_data_o <= 8'h12;		// word 6
		 14: ft_data_o <= 8'h34;		// 

		 15: ft_data_o <= 8'h12;		// word 7
		 16: ft_data_o <= 8'h34;		// 

		 17: ft_data_o <= 8'h12;		// word 8
		 18: ft_data_o <= 8'h34;		// 

		 19: ft_data_o <= 8'h12;		// word 9
		 20: ft_data_o <= 8'h34;		// 

		 21: ft_data_o <= 8'h12;		// word 10
		 22: ft_data_o <= 8'h34;		// 

		 23: ft_data_o <= 8'h12;		// word 11
		 24: ft_data_o <= 8'h34;		// 

		 25: ft_data_o <= 8'h12;		// word 12
		 26: ft_data_o <= 8'h34;		// 

		 27: ft_data_o <= 8'h12;		// word 13
		 28: ft_data_o <= 8'h34;		// 

		 29: ft_data_o <= 8'h12;		// word 14
		 30: ft_data_o <= 8'h34;		// 

		 31: ft_data_o <= 8'h12;		// word 15
		 32: ft_data_o <= 8'h34;		// 

		 33: ft_data_o <= 8'h12;		// word 16
		 34: ft_data_o <= 8'h34;		// 



		 35: ft_data_o <= 8'h00;		// nop



		 36: ft_data_o <= 8'h21;		// write 1 word

		 37: ft_data_o <= 8'h55;		// word 1
		 38: ft_data_o <= 8'haa;		// 



		 39: ft_data_o <= 8'h22;		// write 2 words

		 40: ft_data_o <= 8'haa;		// word 1
		 41: ft_data_o <= 8'h55;		// 

		 42: ft_data_o <= 8'hdc;		// word 2
		 43: ft_data_o <= 8'hab;		// 



       44: ft_data_o <= 8'h11;		// set run mode
		endcase
	
		ft_addr <= ft_addr + 1;
		
		if (ft_addr > 44) begin
		  ft240x_RXF = 1;	// reached end of array
		end
	end
	
	// If the RD line is high, the FT240X's data output is indeterminate
	assign ft240x_d = !ft240x_nRD ? ft_data_o : 8'hXX;

	
	// generate an incrementing pattern for Target CE, OEL and OEH
	reg [3:0] tgtcon_c;
	initial begin
		tgtcon_c = 3'h0;
	end
	
	always @(posedge clk24MHz) begin
		tgtcon_c <= tgtcon_c + 1;
	end
	
	assign tgt_nCE = tgtcon_c[2];
	assign tgt_nOEL = tgtcon_c[1];
	assign tgt_nOEH = tgtcon_c[0];
	
	
	// generate a constantly alternating 55/AA sequence on the address bus
	initial begin
	  addr_bus = 18'h55555;
	end
	
	always @(posedge clk24MHz) begin
	  addr_bus = ~addr_bus;
	end
	
endmodule

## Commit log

2016-11-07 initial import
    [DatatrakEPROMEmu.brd, DatatrakEPROMEmu.sch]
2016-11-12 first routable layout
    [DatatrakEPROMEmu.brd, DatatrakEPROMEmu.sch]
2016-11-14 add status LEDs
    [DatatrakEPROMEmu.brd, DatatrakEPROMEmu.sch]
2016-11-14 fully routed
    [DatatrakEPROMEmu.brd]
2016-11-14 added good-luck pangon to the silkscreen, this had better work
    [DatatrakEPROMEmu.brd]
2016-11-14 fix a few missing routes and ERC errors
    [DatatrakEPROMEmu.brd, DatatrakEPROMEmu.sch]
2016-11-14 remove right-side marker line
    [DatatrakEPROMEmu.brd]
2016-11-14 slight tweaks to silkscreen - move U4 marker line, move IC2 text
    [DatatrakEPROMEmu.brd]
2016-11-15 add net labels, remove TODOs
    [DatatrakEPROMEmu.sch]
2016-11-16 Tag PCBs sent to OSHPark for manufacture
2016-11-16 add missing D_LV8 net between CPLD and SRAM/translator
    OSHPark PCBs had a missing net -- D_LV8 -- the 8th data bit from the level
    translator to the CPLD. These boards will need a greenwire.
    [DatatrakEPROMEmu.brd, DatatrakEPROMEmu.sch]
2016-11-16 Route missing D_LV8 net, bump to Rev B
    [DatatrakEPROMEmu.brd]
2016-11-16 Add TODO - original Datatrak ROM board had two separate ROMs, do we need split hi/lo data enables?
    [DatatrakEPROMEmu.sch]
2016-12-13 Fix to work on final hardware
    * Add testbench and ISIM waveform config
    * Add two hardware test modules (data checkerboard and address loopback)
    Logic changes:
    * Add LEDs - red LED is FTDI activity, yellow is Load mode, green can be
    controlled by the PC.
    * Add FSM command 0x55 and 0xAA to toggle green LED from PC. Intended for
    datapath testing, but also useful as status indication.
    * Latch the data sent by the PC into a write latch before sending to the
    SRAM (because UB# and LB# don't work due to data line reordering done
    during PCB layout).
    * Changes to state machine to honour FT240X FIFO timing requirements.
    * FT240X data bus should be specified as entirely Hi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
    [mrw_test.v, top.v]
2022-07-13 cpld: Initialise mode, exfil-enable and status LED in default state
2022-07-13 cpld: Bugfix: burst writes sometimes cause FSM false command execution
    Burst writes (writes of longer than 1 word) occasionally caused invalid commands to be executed.
    This often manifested as LED state changes / mode changes. (this is more obvious if the LEDs are reconfigured to show `exfiltration_enabled`, `mode[1]` and `mode[0]`).
    Add an extra delay to account for the slight delay while the FT240X makes RXF inactive after the last byte is read.
    [top.v]
2022-07-13 cpld: Improve LED output
    * Add activity blink extend timer (LED holds on for 255 clocks on FTDI activity)
    * Change LED behaviour
    * Red: Exfil enabled, blinks on activity
    * Amber: Status LED, XORed with MODE bit 1. (MODE bit 1 is unused, so this should always show the status LED state)
    * Green: Off for LOAD mode, On for RUN mode
2022-07-13 cpld: Fix minor lint issues highlighted by Verilator
    [top.v]
